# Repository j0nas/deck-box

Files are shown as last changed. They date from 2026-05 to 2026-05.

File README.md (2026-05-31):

# Parametric MTG EDH deck box

A 3D-printable deck box for Magic: The Gathering EDH/Commander decks. Sized for sleeved cards lying flat, ~200 card capacity, with a Voronoi-scale texture and a two-bump snap-fit lid.

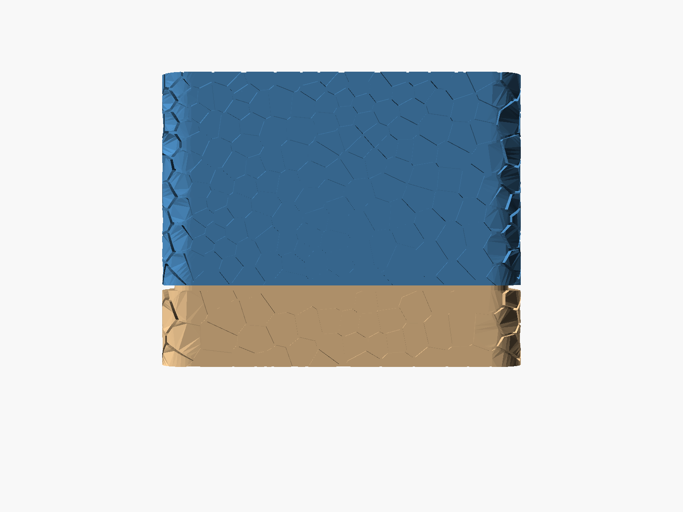
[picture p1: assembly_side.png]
Assembled box


## Features

- **Sleeved-card cavity** — sized by default for 68.3 × 91.3 mm sleeves, 80 mm deck stack (1.5 mm horizontal clearance per side, 1 mm vertical slack). All cavity dimensions are parametric.
- **Voronoi-scale walls** — each cell is a discrete protruding "scale" rather than a continuous bump field, so the smooth wall behind shows through the gaps and the part is paintable as two colors (smooth wall + scales).
- **Two-bump snap-fit** — bumps only on the long sides; release by pinching the short (unbumped) sides to bow the long sides outward.
- **Decorative top + bottom windows** — through-cut frames for visibility / weight / aesthetics.

## Build

Requires [OpenSCAD](https://openscad.org) snapshot/nightly (for the Manifold backend) and Python 3.10+.

```bash
brew install --cask openscad@snapshot          # macOS — use your package manager elsewhere
python -m venv .venv && source .venv/bin/activate
pip install -r requirements.txt
bash build.sh
```

`build.sh` regenerates the Voronoi scale data (`seam.scad`) from `seam.py`, then renders `base.stl`, `lid.stl`, and two preview PNGs. End-to-end: about 3 seconds.

## Customizing

Common parameters to tune in `deckbox.scad`:

| Param | Default | Effect |
|---|---|---|
| `CAV_W`, `CAV_D`, `CAV_H` | 94.3, 71.3, 81.0 | Cards cavity dimensions (mm). Resize for different sleeves or stack heights. |
| `H_TOL` | 0.3 | Lid-over-base horizontal slide-fit clearance per side. Loosen on tight printers, tighten on sloppy ones. Also reduces snap-fit bump engagement by the same amount. |
| `LOCK_BUMP_R` | 0.9 | Snap-fit bump protrusion. Effective engagement = `LOCK_BUMP_R − H_TOL`. Smaller = easier release, looser hold. |
| `WIDE_WALL_T`, `NARROW_WALL_T` | 3.92, 1.86 | Wall thicknesses for the base wide and narrow sections. |

If you change `CAV_W`, `CAV_D`, `CAV_H`, `WIDE_WALL_T`, `NARROW_WALL_T`, `FLOOR_T`, `CEILING_T`, `SEAM_Z`, or `VERTICAL_GAP`, mirror the same value into `seam.py` — the Voronoi geometry needs to align with the wall geometry.

In `seam.py`:

| Param | Default | Effect |
|---|---|---|
| `CELL_DENSITY` | 0.026 cells/mm² | Scale density. Higher = smaller, more numerous scales. |
| `SCALE_PROTRUSION` | 1.5 | How far each scale sticks out from the smooth wall (mm). |
| `SCALE_GAP` | 0.4 | Width of the smooth-wall "grout" between adjacent scales (mm). |
| `SCALE_OVERLAP` | 0.3 | How far each scale extends into the wall material (for clean union). |

## Printing

- **Material**: PLA or PETG. Both work; PETG snap-fit is slightly more forgiving.
- **Layer height**: 0.2 mm.
- **Orientation**: base open-side-up, lid open-cavity-up. Both parts have flat undersides — no supports needed.
- **Infill**: 15 – 20 % is plenty.
- **First layer**: nothing special; the protruding scales start above the build plate.

To paint the dual-color effect, drybrush the protruding scale tops in a contrasting color after the part is printed in a single material. The 0.4 mm "grout" gaps stay the base color.

## How it works

- `deckbox.scad` builds the box, lid, cavity, windows, and snap-fit bumps as plain OpenSCAD primitives.
- `seam.py` runs a Voronoi tessellation in arc-length-along-perimeter × height space, then maps each cell back onto the curved outer wall and emits each one as a `polyhedron(...)` with explicit vertices and faces — Manifold handles ~600 of these in well under a second.
- `seam.scad` is the generated include with two modules: `base_teeth()` and `lid_teeth()`. `deckbox.scad` unions them into the respective parts.

The split between Python and OpenSCAD is deliberate: Voronoi and polygon offset are easy in Python (scipy + shapely) and miserable in OpenSCAD, while CSG of the box body is the other way around.

See [`CLAUDE.md`](CLAUDE.md) for the gotcha list — useful if you (or an AI assistant) start modifying the scale geometry.

## License

MIT. See [LICENSE](LICENSE).

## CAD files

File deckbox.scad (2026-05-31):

// MTG EDH deck box — OpenSCAD / Manifold parametric model.
//
// Coordinate convention:
//   z = 0 is the cards-cavity floor.
//   Base bottom at z = -FLOOR_T (negative).
//   Cards cavity top at z = CAV_H.
//   Lid top at z = CAV_H + CEILING_T.
//
// Build:
//   python seam.py                                          # regenerate Voronoi data
//   openscad --backend=Manifold -o base.stl     -D 'mode="base"'     deckbox.scad
//   openscad --backend=Manifold -o lid.stl      -D 'mode="lid"'      deckbox.scad
//   openscad --backend=Manifold -o assembly.png \
//        --imgsize=1600,1200 --colorscheme=Tomorrow \
//        -D 'mode="assembly"' deckbox.scad

include <seam.scad>

// === Parameters (mm) =========================================================

// Cavity sized for sleeved cards 68.3 × 91.3 mm + 3 mm total clearance per
// horizontal axis (1.5 mm per side) and an 80 mm card stack + 1 mm vertical
// slack so the top card slides in cleanly.
CAV_W = 94.3;          // cards cavity inner width  (X) — card 91.3 + 3
CAV_D = 71.3;          // cards cavity inner depth  (Y) — card 68.3 + 3
CAV_H = 81.0;          // cards cavity inner height (Z) — deck 80 + 1
CAV_R = 3.92;          // cavity vertical corner radius

WIDE_WALL_T   = 3.92;  // base wide-section wall thickness
NARROW_WALL_T = 1.86;  // narrow section / lid wall thickness
FLOOR_T       = 1.86;  // base bottom thickness
CEILING_T     = 1.86;  // lid top thickness

SEAM_Z        = 20.0;  // base shoulder height above cavity floor
VERTICAL_GAP  = 1.5;   // visible vertical gap between base top and lid bottom
LID_BOTTOM_Z  = SEAM_Z + VERTICAL_GAP;  // 21.5

H_TOL = 0.3;           // horizontal print tolerance (lid cavity larger per side)

// Decorative window dimensions — sized to preserve a 5.8 mm frame border
// on each side of the cavity (so WIN = CAV − 11.6).
WIN_W = 82.7;
WIN_D = 59.7;
WIN_R = 2.5;

// === Derived =================================================================

BOX_W       = CAV_W + 2 * WIDE_WALL_T;       // 100.84
BOX_D       = CAV_D + 2 * WIDE_WALL_T;       // 75.84
NARROW_W    = CAV_W + 2 * NARROW_WALL_T;     // 96.72
NARROW_D    = CAV_D + 2 * NARROW_WALL_T;     // 71.72
LID_CAV_W   = NARROW_W + 2 * H_TOL;          // 97.32
LID_CAV_D   = NARROW_D + 2 * H_TOL;          // 72.32

BASE_BOT_Z  = -FLOOR_T;                      // -1.86
LID_TOP_Z   = CAV_H + CEILING_T;             // 72.86

// Outer fillet radii — uniform wall thickness around the corners.
WIDE_OUTER_R   = CAV_R + WIDE_WALL_T;        // 7.84
NARROW_OUTER_R = CAV_R + NARROW_WALL_T;      // 5.78
LID_CAV_R      = NARROW_OUTER_R + H_TOL;     // 6.08
LID_OUTER_R    = WIDE_OUTER_R;               // 7.84

$fn = 36;   // facet count for circles/cylinders

// === Helper modules ==========================================================

// 2D rounded rectangle (hull of 4 corner circles, all of radius r)
module rounded_rect(w, d, r) {
    hull() {
        translate([ r - w/2,  r - d/2]) circle(r=r);
        translate([ w/2 - r,  r - d/2]) circle(r=r);
        translate([ r - w/2,  d/2 - r]) circle(r=r);
        translate([ w/2 - r,  d/2 - r]) circle(r=r);
    }
}

// 3D rounded box, extruded along Z from z_bot upward by h.
module rounded_box(w, d, h, r, z_bot=0) {
    translate([0, 0, z_bot])
        linear_extrude(height=h)
            rounded_rect(w, d, r);
}

// Through-hole window: cuts a rounded rectangle through the full extent.
module window_cut(w, d, h, r, z_bot) {
    rounded_box(w, d, h, r, z_bot);
}

// === Parts ===================================================================

// (Scales now PROTRUDE from a smooth wall — no shell carve needed.)

// Snap-fit locking bumps: small spheres on the narrow section's outer wall
// at LOCK_BUMP_Z. The lid has matching spherical cavities — when assembled,
// the lid flexes slightly over the bumps and clicks into place.
LOCK_BUMP_R   = 0.9;    // bump protrusion radius (mm) — engagement = R − H_TOL
LOCK_CAV_R    = 0.95;   // matching cavity radius (≈0.05mm play once snapped)
LOCK_BUMP_Z   = (SEAM_Z + CAV_H) / 2;  // mid-height of the narrow section (≈45)

// One bump per LONG side only (at y = ±NARROW_D/2). Squeezing the short
// (unbumped) sides bows the long sides outward at their midpoints, popping
// the bumps free of their cavities — that's the lid-release motion.
module lock_bumps() {
    translate([0, -NARROW_D/2, LOCK_BUMP_Z]) sphere(r=LOCK_BUMP_R);
    translate([0, +NARROW_D/2, LOCK_BUMP_Z]) sphere(r=LOCK_BUMP_R);
}

module lock_cavities() {
    translate([0, -NARROW_D/2, LOCK_BUMP_Z]) sphere(r=LOCK_CAV_R);
    translate([0, +NARROW_D/2, LOCK_BUMP_Z]) sphere(r=LOCK_CAV_R);
}

// Base body: smooth outer wall + protruding Voronoi scales.
module base() {
    union() {
        difference() {
            union() {
                rounded_box(BOX_W, BOX_D, SEAM_Z - BASE_BOT_Z, WIDE_OUTER_R, BASE_BOT_Z);
                rounded_box(NARROW_W, NARROW_D, CAV_H - SEAM_Z, NARROW_OUTER_R, SEAM_Z);
                lock_bumps();
            }
            rounded_box(CAV_W, CAV_D, CAV_H + 0.5, CAV_R, 0);
            window_cut(WIN_W, WIN_D, FLOOR_T + 1.0, WIN_R, BASE_BOT_Z - 0.5);
        }
        // base_teeth is already clipped to z ≤ SEAM_Z in seam.py.
        base_teeth();
    }
}

// Lid body: smooth outer wall + protruding Voronoi scales.
module lid() {
    union() {
        difference() {
            rounded_box(BOX_W, BOX_D, LID_TOP_Z - LID_BOTTOM_Z, LID_OUTER_R, LID_BOTTOM_Z);
            rounded_box(LID_CAV_W, LID_CAV_D, CAV_H - LID_BOTTOM_Z + 0.01, LID_CAV_R, LID_BOTTOM_Z);
            window_cut(WIN_W, WIN_D, CEILING_T + 1.0, WIN_R, CAV_H - 0.5);
            lock_cavities();
        }
        // lid_teeth is already clipped to [LID_BOTTOM_Z, LID_TOP_Z] in seam.py.
        lid_teeth();
    }
}

// === Entry point — render based on `mode` variable ===========================

mode = "assembly";   // override with -D 'mode="base"' or 'mode="lid"'

if (mode == "base") {
    base();
} else if (mode == "lid") {
    lid();
} else if (mode == "exploded") {
    color("burlywood") base();
    translate([0, 0, 30]) color("steelblue") lid();
} else {
    color("burlywood") base();
    color("steelblue") lid();
}

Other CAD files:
seam.scad

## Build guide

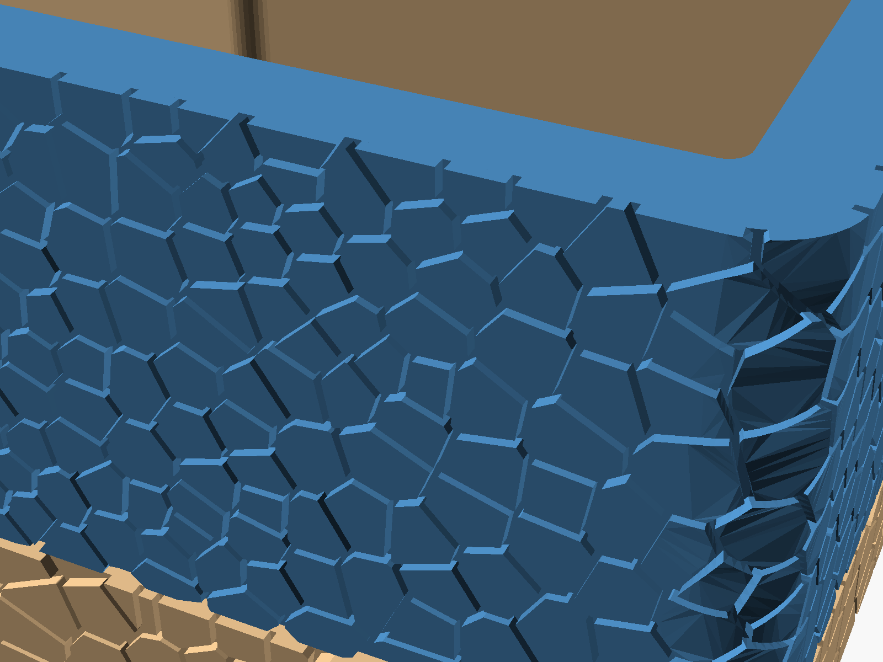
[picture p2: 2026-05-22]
assembly_iso.png

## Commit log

2026-05-22 Initial commit: parametric MTG EDH deck box
    Parametric design in OpenSCAD + Python:
    - deckbox.scad: rounded base + lid bodies, decorative windows, snap-fit
    - seam.py: Voronoi preprocessor, emits seam.scad with protruding scales
    - build.sh: regenerate seam + render STLs and assembly previews (~3s)
    Geometry:
    - Cavity sized for 68.3 x 91.3 mm sleeved cards, 80 mm deck stack
    (1.5 mm horizontal clearance per side, 1 mm vertical slack)
    - Outer fillets keep wall thickness uniform around vertical corners
    - H_TOL = 0.4 mm per-side lid-over-base slide fit
    - Snap-fit bumps on long sides only; pinch short sides to release
    Voronoi scales:
    - Density-matched base/lid tessellations (CELL_DENSITY cells/m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
    [deckbox.scad, seam.scad]
2026-05-22 Add README, MIT license, requirements.txt; clean up dead code
    Cleanups:
    - Drop WAVE_AMP (unused since wave-seam design was replaced)
    - Drop TEETH_DEPTH, SEAM_Z_MIN, SEAM_Z_MAX, SEAM_BAND_HALF (legacy aliases)
    - Drop CELLS_Z_MAX overshoot (+6 was for old clip-trim approach)
    - Delete unused functions: _unused_voronoi_edge_samples, perimeter_arc_starts
    - Stop emitting unused globals (SCALE_PROTRUSION/_OVERLAP, SEAM_Z_MIN/MAX)
    and the voronoi_cutters() empty stub in seam.scad
    Docs:
    - README.md: features, build, customization params, print tips, design
    rationale, link to CLAUDE.md gotcha list
    - LICENSE: MIT
    - requirements.txt: numpy / scipy / shapely minimums
    - .gitignore: also exclude .clau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
    [deckbox.scad, seam.scad]
2026-05-31 Tighten snap-fit and add optional STEP export
    H_TOL 0.4 → 0.3 and LOCK_BUMP_R 0.7 → 0.9 (engagement now 0.6 mm) for
    a firmer lid click. New `build.sh --step` flag exports assembled BRep
    via OpenSCAD CSG → freecadcmd csg_to_step.py → assembly.step.
    [deckbox.scad]
